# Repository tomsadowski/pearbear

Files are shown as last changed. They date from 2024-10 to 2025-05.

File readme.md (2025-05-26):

# Pearbear
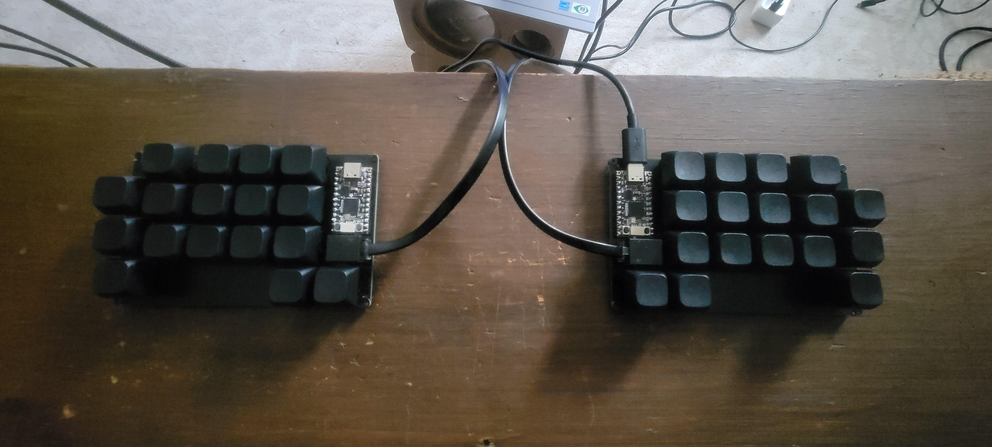
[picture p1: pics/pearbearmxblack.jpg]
pearbears

2) Order the PCB
  * 1) Download the [specification file](mx/production/pearbear_mx.zip)
  * 2) Upload the file to a PCB [fabrication service](https://jlcpcb.com/)
3) Bill of Materials
  * a) 2x [Adafruit KB2040](https://www.adafruit.com/product/5302#tutorials)
    * product id: 5302
    * [datasheet](datasheets/Adafruit_KB2040_Pinout.pdf)
  * b) 2x [6P6C RJ11 socket](https://www.digikey.com/en/products/detail/w%C3%BCrth-elektronik/615006138421/2060609) 
    * manufacturer product number: 615006138421
    * digikey part number: 732-2113-ND
    * [datasheet](datasheets/WR-MJ.pdf)
  * c) 2x [6mm B3F-10xx tactile switches](https://www.digikey.com/en/products/detail/adafruit-industries-llc/367/10669771)
    * manufacturer product number: 367
    * digikey part number: 1528-367-ND
    * [datasheet](datasheets/B3F-1000-Omron.pdf)
  * d) 34x [Cherry MX switches](https://mechanicalkeyboards.com/products/cherry-mx2a-silent-red-45g-linear)
    * [datasheet](datasheets/Cherry_MX.pdf)
  * e) 34x [XDA Keycaps](https://ymdkey.com/products/xda-1u-new-keycapsblank-pbt-1-55mm)
  * f) Substrate
    * 1x Mousepad
    * 12x M2 screws
    * 12x M2 hex nuts
    * Needle and thread  
4) Assembly
  * 1) Solder 3.a - 3.d to PCB (beginners guide pending)
  * 2) Stitch mousepad to PCB using 3.e
5) Flash microcontrollers with [QMK firmware](https://github.com/tomsadowski/pearbear_qmk_firmware)

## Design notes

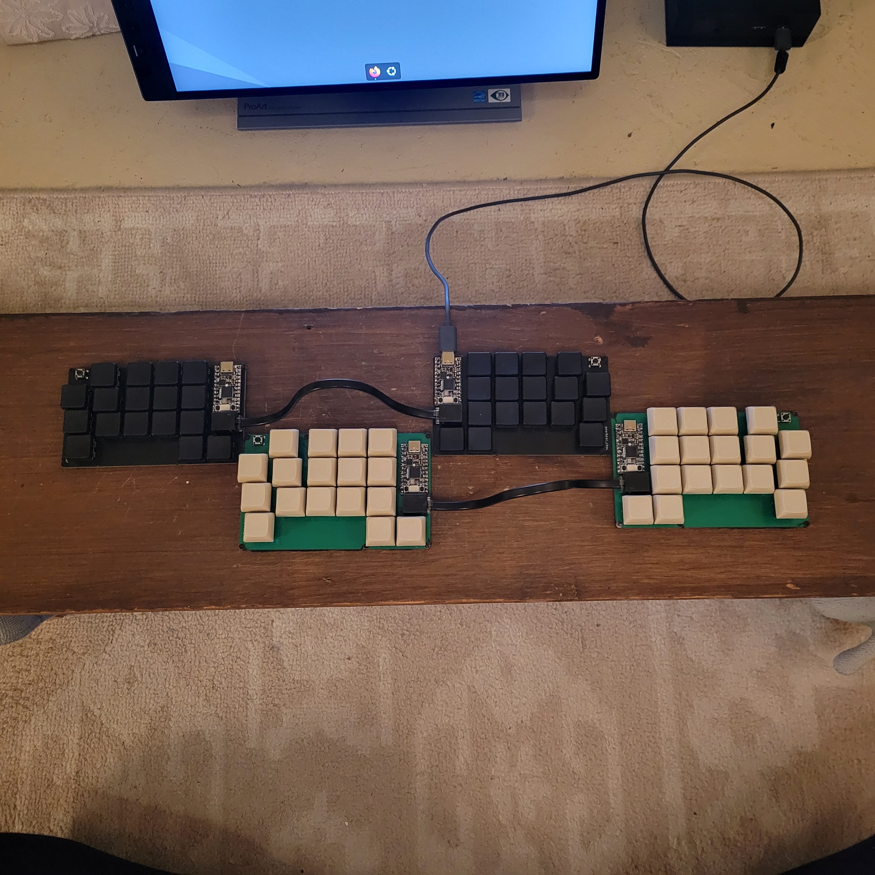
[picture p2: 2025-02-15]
pics/pearbears.jpg

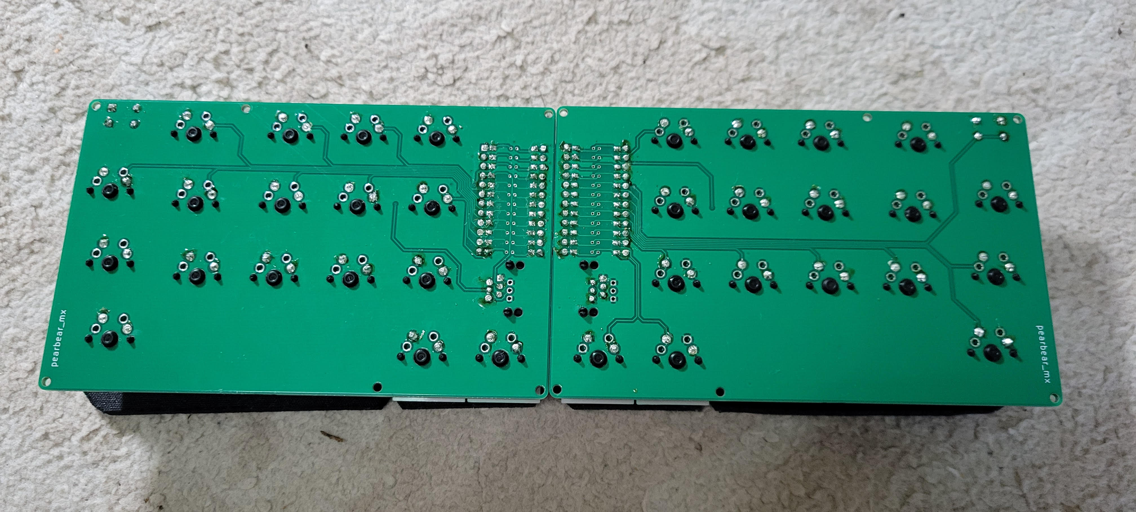
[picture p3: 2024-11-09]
pics/pearbear_mx_joints.jpg

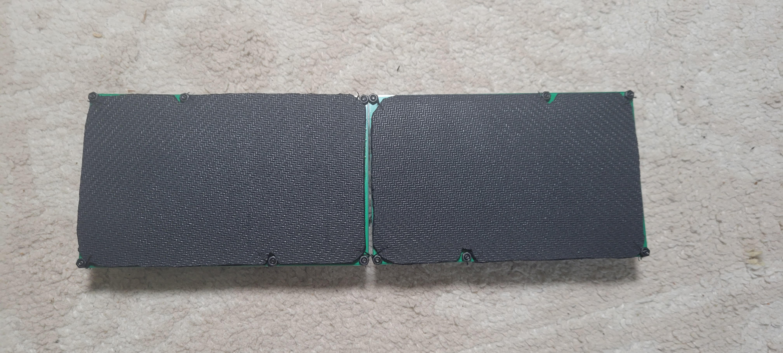
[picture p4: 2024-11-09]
pics/pearbear_mx_bottom.jpg

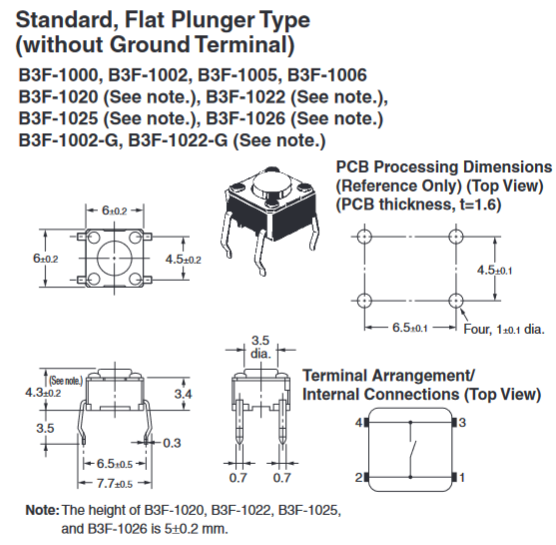
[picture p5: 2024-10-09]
datasheets/Reset_Switch_BF3.png

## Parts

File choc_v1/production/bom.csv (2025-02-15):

Designator | Footprint | Quantity | Value | LCSC Part #
J1 | RJ11_6P6C_reversible | 1 | rj11
SW1, SW10, SW11, SW12, SW13, SW14, SW15, SW16, SW17, SW2, SW3, SW4, SW5, SW6, SW7, SW8, SW9 | SW_Kailh_Choc_v1_reversible | 17 | SW_Push
SW_RESET1 | SW_TH_Tactile_Omron_B3F-10xx_reversible | 1 | SW_Push
U1 | ProMicro_reversible | 1 | ProMicro-kbd-rev

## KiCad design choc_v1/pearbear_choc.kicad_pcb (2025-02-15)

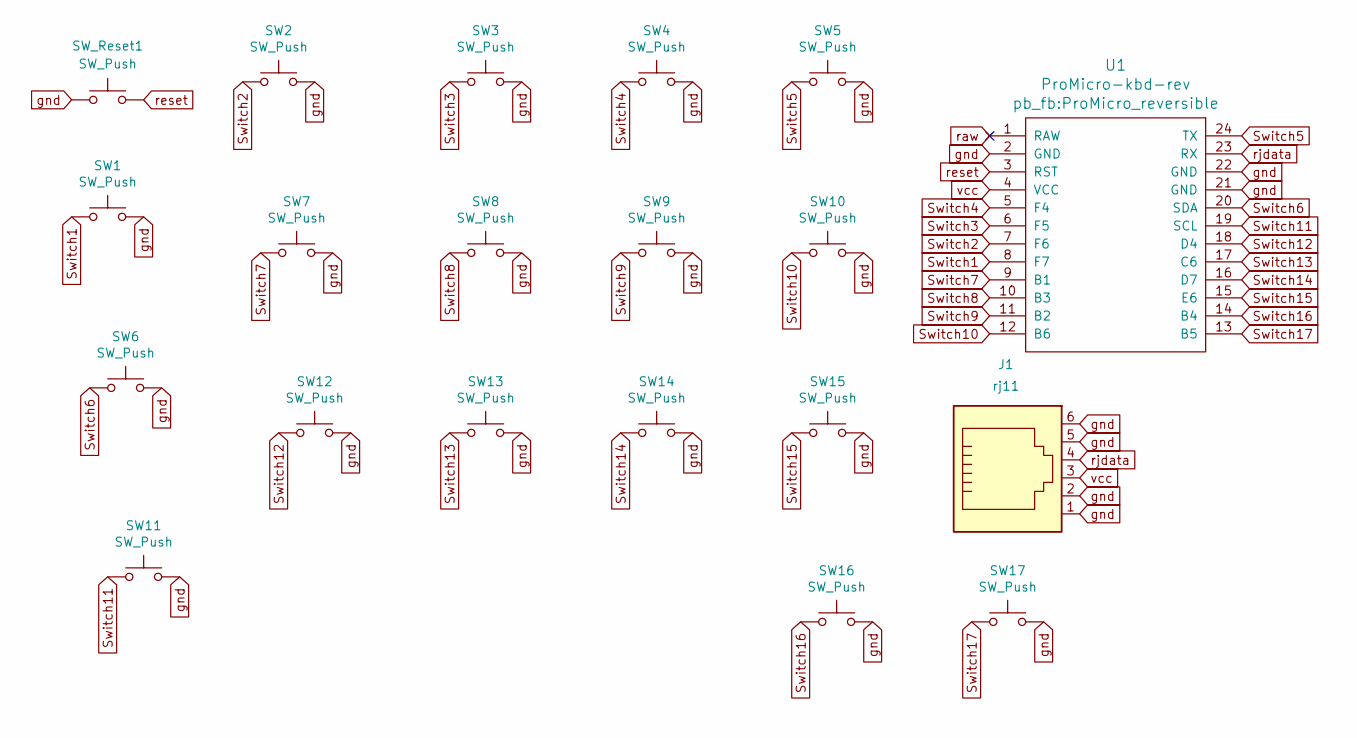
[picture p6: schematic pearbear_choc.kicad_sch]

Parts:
J1: rj11; RJ11_6P6C_reversible
SW1, SW2, SW3, SW4, SW5, SW6, SW7, SW8, SW9, SW10, SW11, SW12, SW13, SW14, SW15, SW16, SW17: SW_Push; SW_Kailh_Choc_v1_reversible
SW_Reset1: SW_Push; SW_TH_Tactile_Omron_B3F-10xx_reversible
U1: ProMicro-kbd-rev; ProMicro_reversible

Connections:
Switch1: SW1.1, U1.8 (F7)
Switch2: SW2.1, U1.7 (F6)
Switch3: SW3.1, U1.6 (F5)
Switch4: SW4.1, U1.5 (F4)
Switch5: SW5.1, U1.24 (TX)
Switch6: SW6.1, U1.20 (SDA)
Switch7: SW7.1, U1.9 (B1)
Switch8: SW8.1, U1.10 (B3)
Switch9: SW9.1, U1.11 (B2)
Switch10: SW10.1, U1.12 (B6)
Switch11: SW11.1, U1.19 (SCL)
Switch12: SW12.1, U1.18 (D4)
Switch13: SW13.1, U1.17 (C6)
Switch14: SW14.1, U1.16 (D7)
Switch15: SW15.1, U1.15 (E6)
Switch16: SW16.1, U1.14 (B4)
Switch17: SW17.1, U1.13 (B5)
gnd: J1.1, J1.2, J1.5, J1.6, SW1.2, SW2.2, SW3.2, SW4.2, SW5.2, SW6.2, SW7.2, SW8.2, SW9.2, SW10.2, SW11.2, SW12.2, SW13.2, SW14.2, SW15.2, SW16.2, SW17.2, SW_Reset1.1, U1.2 (GND), U1.21 (GND), U1.22 (GND)
raw: U1.1 (RAW)
raw_1: U1.1 (RAW)
raw_2: U1.1 (RAW)
raw_3: U1.1 (RAW)
raw_4: U1.1 (RAW)
reset: SW_Reset1.2, U1.3 (RST)
rjdata: J1.4, U1.23 (RX)
vcc: J1.3, U1.4 (VCC)

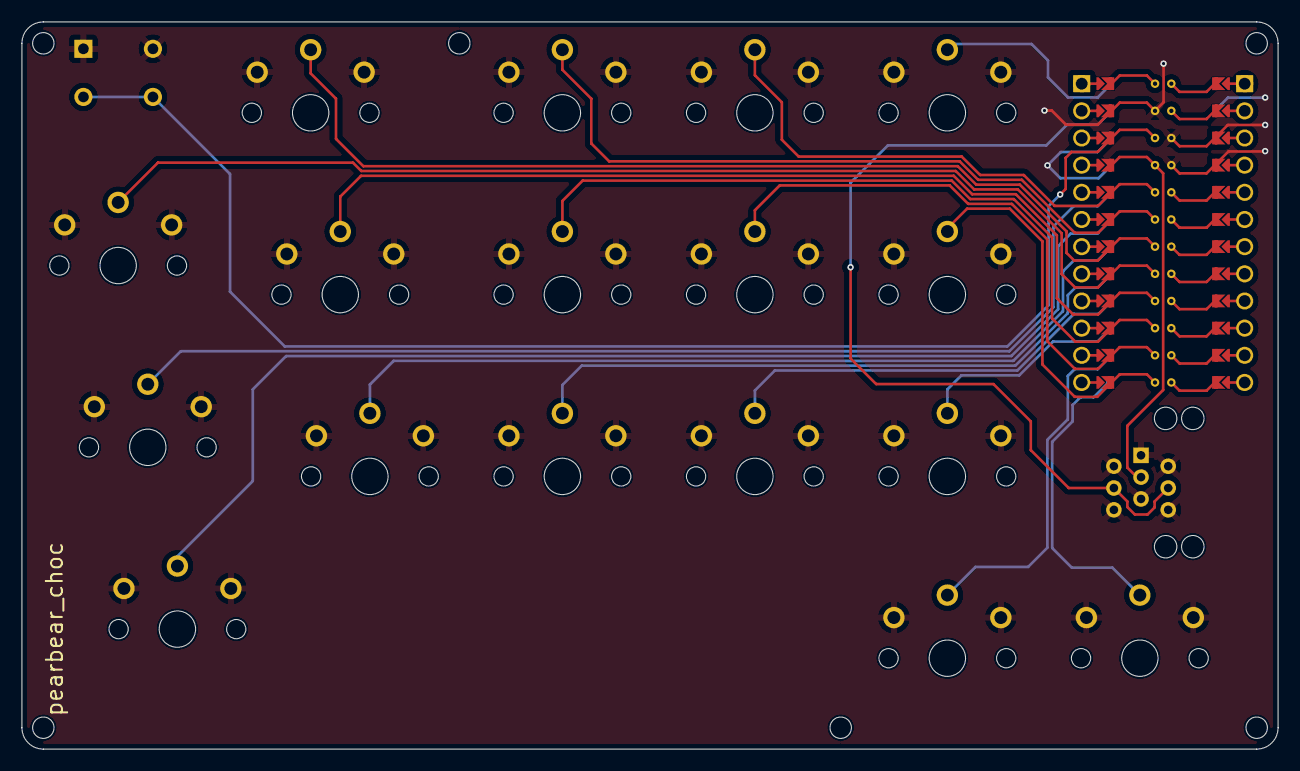
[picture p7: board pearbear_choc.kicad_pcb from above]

Board: 2 copper layers, 117.5 x 68.0 mm, 20 parts (0 on the bottom side), 21 nets.

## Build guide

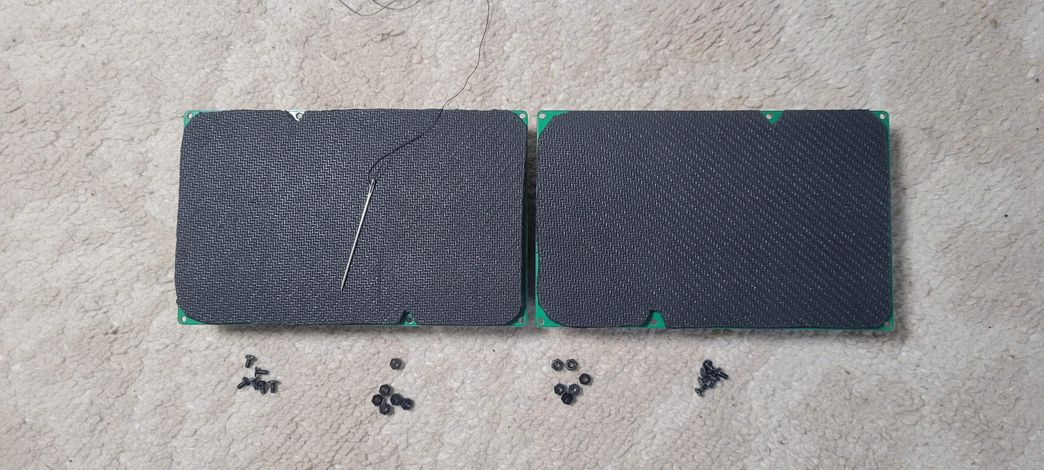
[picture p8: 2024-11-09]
pics/pearbear_mx_bottom_setup.jpg
